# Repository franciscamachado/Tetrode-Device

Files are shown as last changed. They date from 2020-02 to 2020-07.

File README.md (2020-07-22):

# Tetrode-Device

We have developed a simple and affordable tetrode-based device that allows interchangeable extracellular recordings of neural activity between in vivo and ex vivo preparations and can be easily implemented in all wet-bench laboratories.

All

## Building Instructions
Construction and usage are described in the [paper](https://www.sciencedirect.com/science/article/pii/S0165027020301783).

**Assembly Parts:**

**(1) - Electrode Interface Board (EIB).** The EIB's gerber files are provided in the "Design" folder for three different headstages: (1) RHD32 (Intan/Open Ephys) ([link](https://github.com/franciscamachado/Tetrode-Device/tree/master/Designs/EIB/Eagle/OpenEphys)), (2) HS-36-LED (NeuraLynx) ([link](https://github.com/franciscamachado/Tetrode-Device/tree/master/Designs/EIB/Eagle/Neuralynx)) and (3) HST/32D Plexon ([link](https://github.com/franciscamachado/Tetrode-Device/tree/master/Designs/EIB/Eagle/Plexon)). Each EIB is provided intwo versions: the first with independent GND and REF and the second with shorted GND and REF. The EIB should be manufactured with electroless nickel immersion gold (ENIG) surface finishing.

**(2) - A79024-001 Omnetics connector** ([link](https://www.omnetics.com/products/neuro-connectors/nano-strip-connectors)). 

**(3) - Small gold pins** ([link](https://neuralynx.com/hardware/small-eib-pins)). 

**(4) - Tetrode guide.** The .STL files of the tetrode guide are available with 2 single track widths: 0.3 mm ([link](https://github.com/franciscamachado/Tetrode-Device/blob/master/Designs/Tetrode%20Guide/0.3mmTrack.stl)) and 0.6 mm ([link](https://github.com/franciscamachado/Tetrode-Device/blob/master/Designs/Tetrode%20Guide/0.6mmTrack.stl)). An .STL file for the tetrode guide with an optogenetic extention is also available ([link](https://github.com/franciscamachado/Tetrode-Device/tree/master/Designs/Tetrode%20Guide/Optogenetic%20Extension)). These designs are easily altered and adjusted to the size and number of tetrodes to be used.

**(5) - Tetrode wire** (depending on application).

## Citing this Work

When using this device, please cite the paper:

Francisca Machado, Nuno Sousa, Patricia Monteiro, Luis Jacinto (2020). A versatile and modular tetrode-based device for single-unit recordings in rodent ex vivo and in vivo acute preparations. J Neurosci Methods, 341:108755. [Link](https://www.sciencedirect.com/science/article/pii/S0165027020301783)

## License

<br />This work is licensed with a License <a rel="license" href="http://creativecommons.org/licenses/by-nc/4.0/">Creative Commons - Attribution-NonCommercial 4.0 International</a>.

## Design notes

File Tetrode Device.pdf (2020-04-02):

Tetrode Device | 1

1

Assembly Parts:
(1) – Electrode Interface Board (EIB). Link (https://github.com/franciscamachado/Tetrode-Device/tree/master/Designs/EIB)
(2) – A79024-001 Omnetics connector. Link (https://www.omnetics.com/products/neuro-connectors/nano-strip-connectors)
(3) – Small gold pins. Link (https://neuralynx.com/hardware/small-eib-pins)
(4) – Tetrode guide. Link (https://github.com/franciscamachado/Tetrode-Device/tree/master/Designs/Tetrode%20Guide)
(5) – Tetrode wire (determined by application).

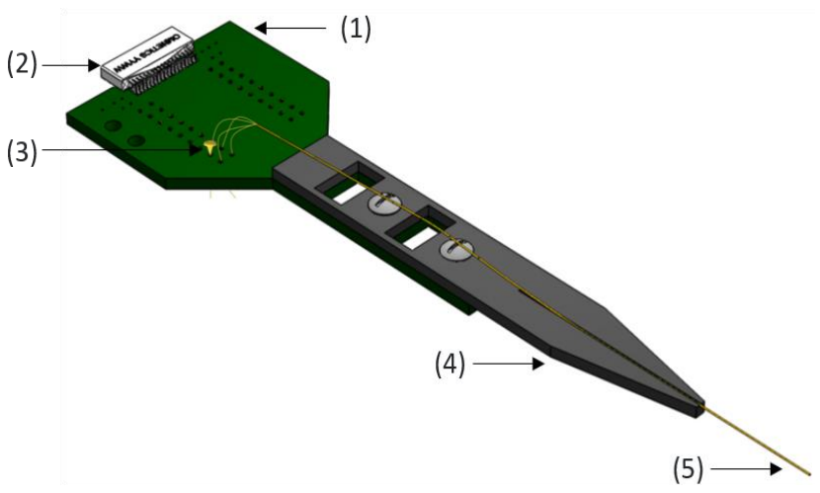
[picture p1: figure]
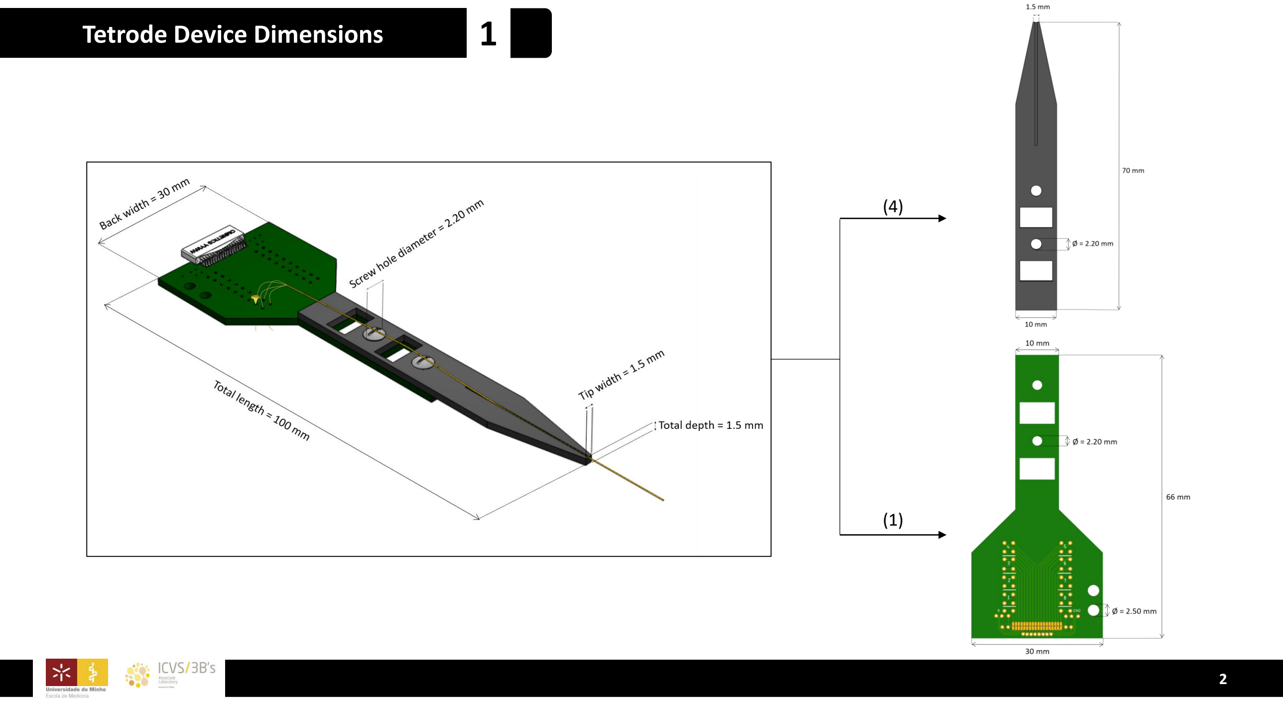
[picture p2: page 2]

Tetrode Device Dimensions | 1

2

(1)

(4)

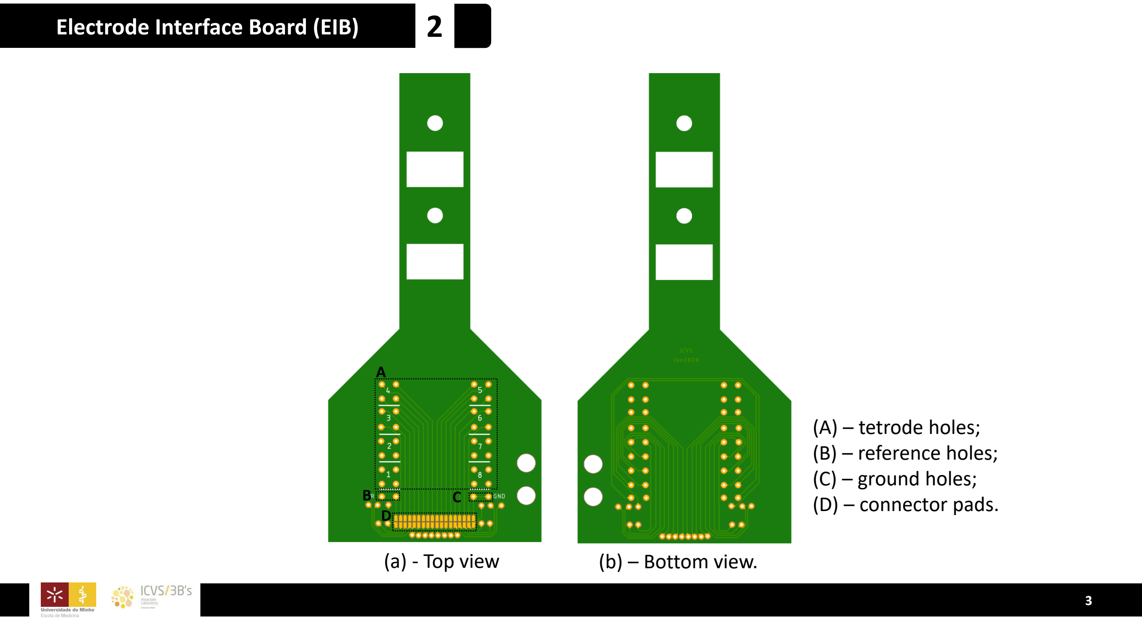
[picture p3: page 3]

Electrode Interface Board (EIB) 2

3

(A) – tetrode holes;
(B) – reference holes;
(C) – ground holes;
(D) – connector pads.
(a) - Top view | (b) – Bottom view.

A

B C
D

4

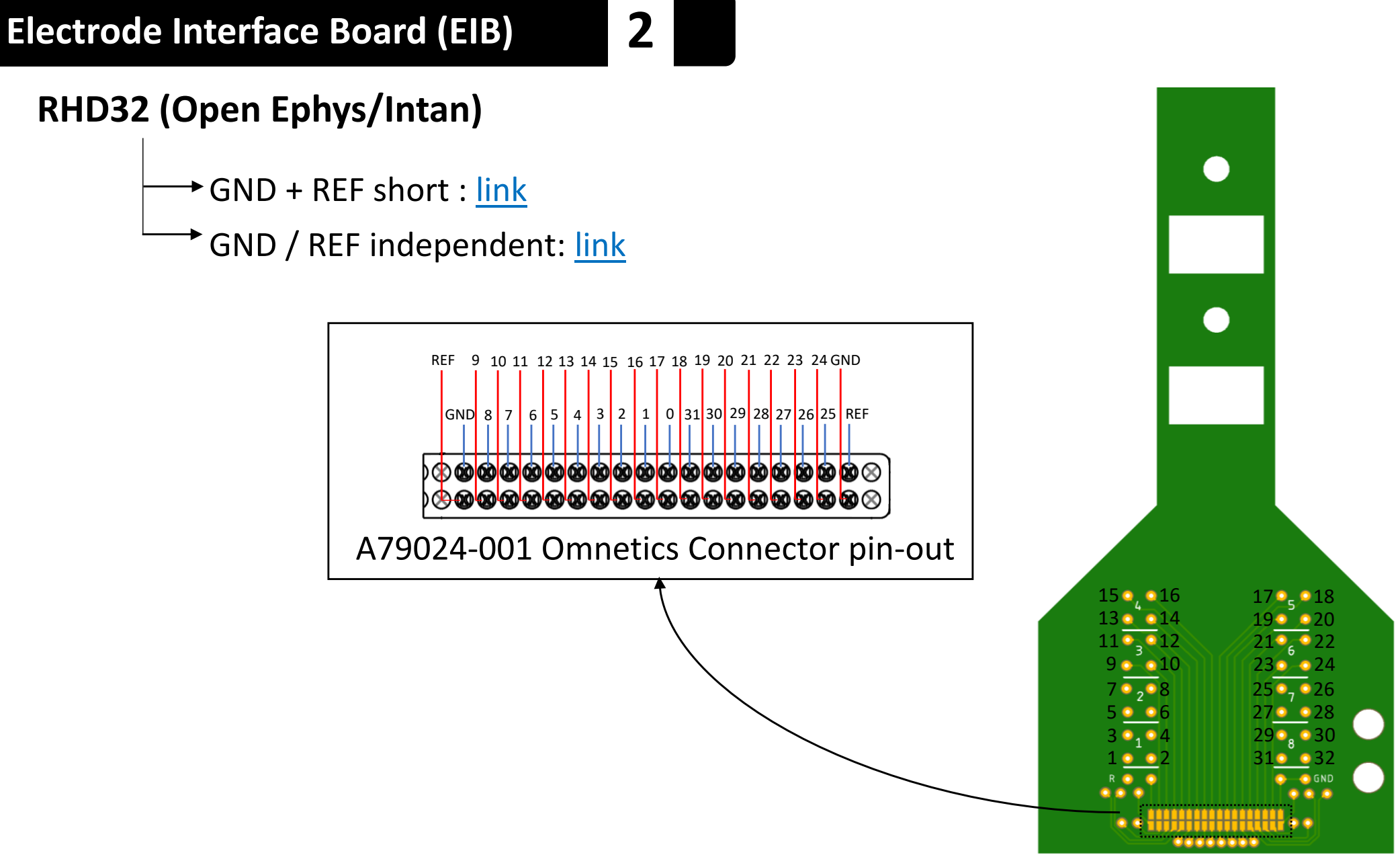
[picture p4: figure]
Electrode Interface Board (EIB); GND; REF; 24 GND; A79024-001 Omnetics Connector pin-out; RHD32 (Open Ephys/Intan); GND + REF short : link; GND / REF independent: link

(a) Top view

9 10 11 12 13 14 15 16 17 18 19 20 21 22 23

5

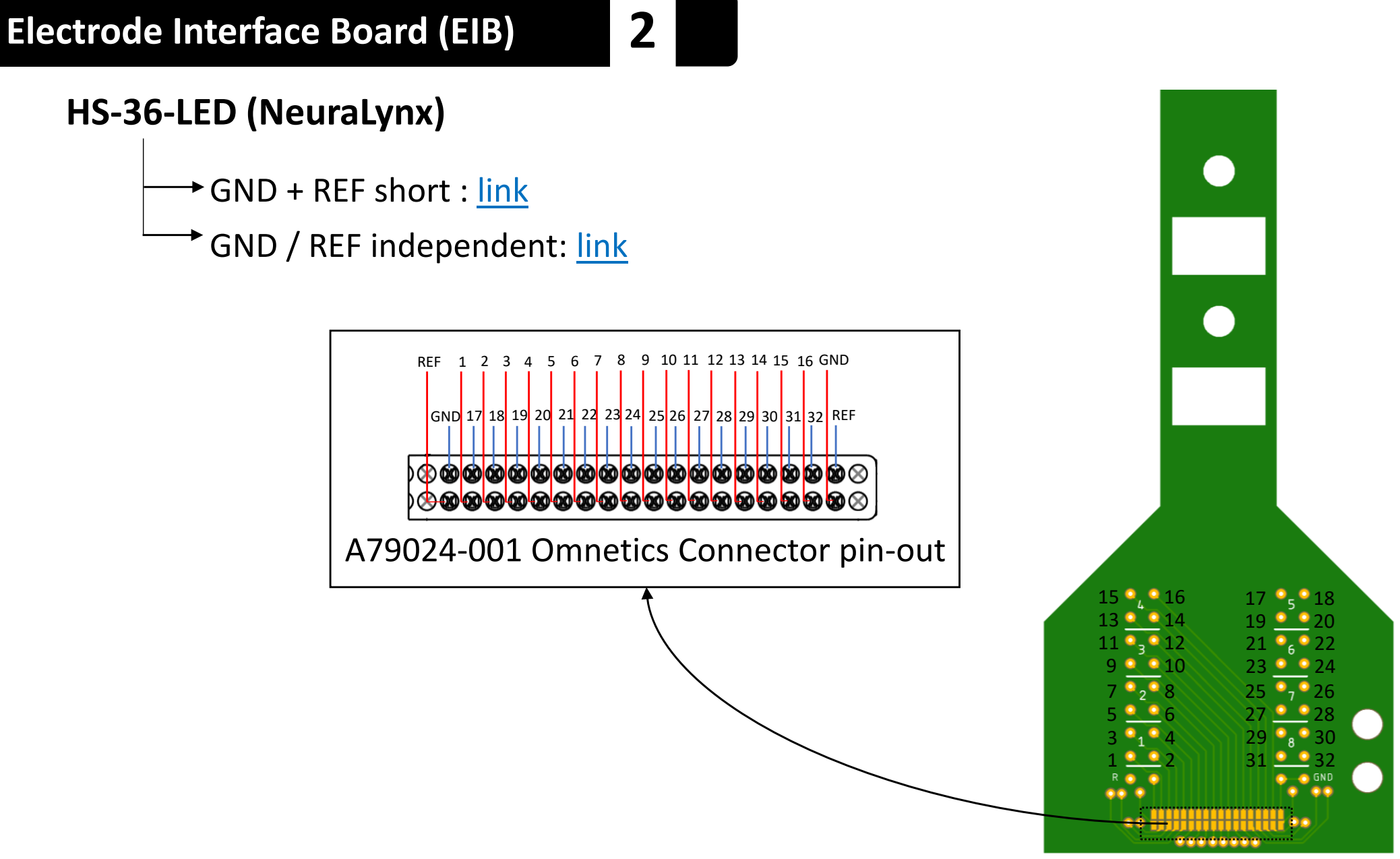
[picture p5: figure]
Electrode Interface Board (EIB); GND; REF; 8 9 10 11 12 13 14 15 16 GND; HS-36-LED (NeuraLynx); A79024-001 Omnetics Connector pin-out; GND + REF short : link; GND / REF independent: link

(a) Top view

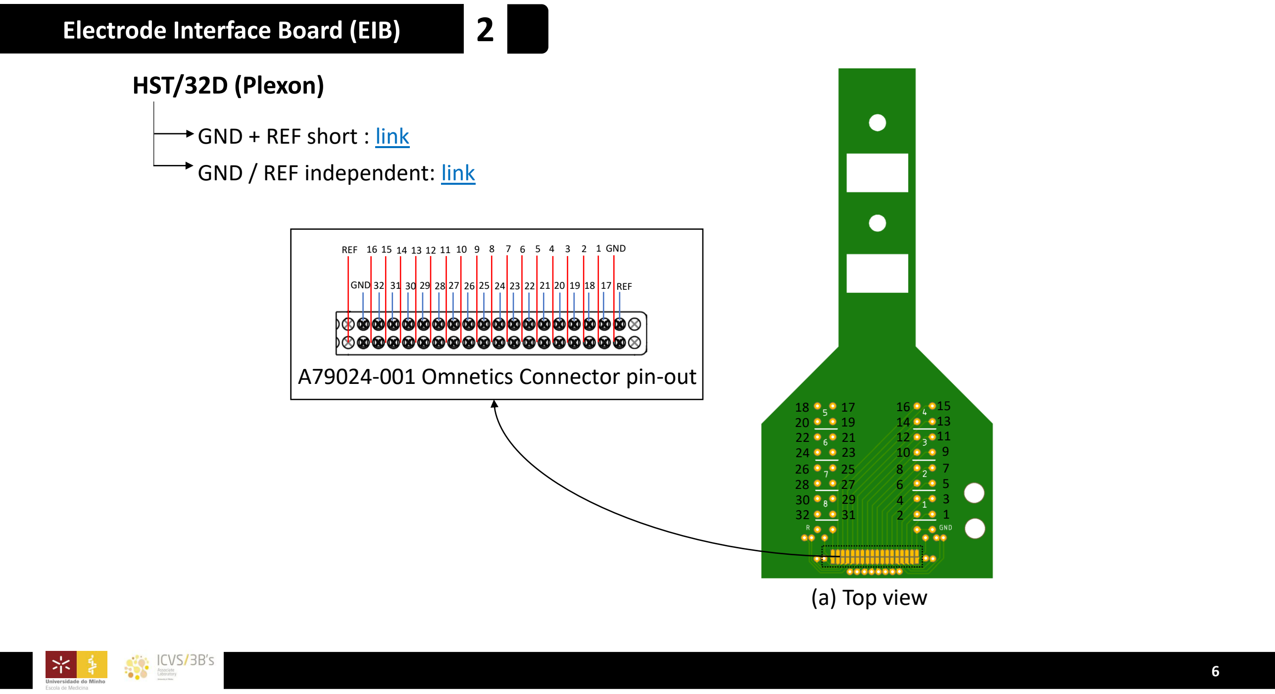
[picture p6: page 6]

Electrode Interface Board (EIB) 2

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
14 | 13
16 | 15
20 | 19
18 | 17
24 | 23
22 | 21
28 | 27
26 | 25
32 | 31
30 | 29
(a) Top view

HST/32D (Plexon)

REF 16 15 14 13 12 11 10 9 8 7 6 5 4 3 2 1 GND

GND 32 | 31 | 30 | 29 | 28 27 | 26 | 25 | 24 | 23 | 22 | 21 | 20 | 19 | 18 | 17 | REF

A79024-001 Omnetics Connector pin-out

GND + REF short : link (https://github.com/franciscamachado/Tetrode-Device/tree/master/Designs/EIB/Eagle/Plexon/GND%20%26%20REF%20shorted)
GND / REF independent: link (https://github.com/franciscamachado/Tetrode-Device/tree/master/Designs/EIB/Eagle/Plexon/GND%20%26%20REF)

Tetrode Guide | 3

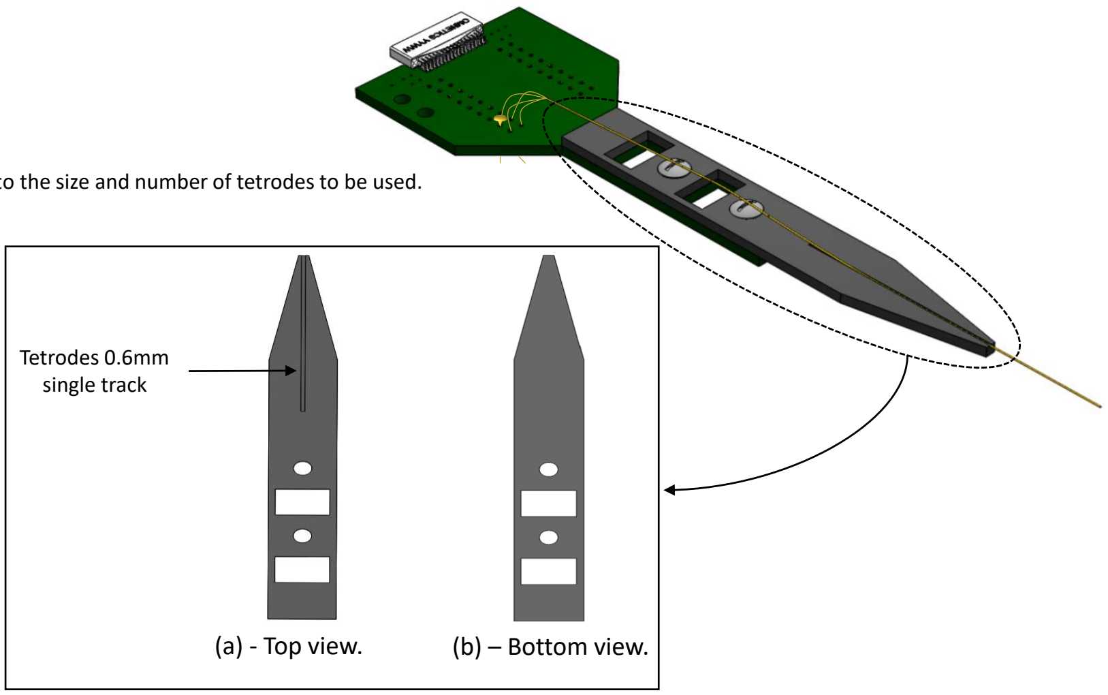
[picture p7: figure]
Tetrodes 0.6mm single track; (a) - Top view.; (b) – Bottom view.

7

Tetrode guide - single track example (holds 8x50µm tetrodes):
- length = 30 mm
- width = 0.6 mm
- depth= 0.6 mm

* These designs are easily altered and adjusted to the size and number of tetrodes to be used. Link (https://github.com/franciscamachado/Tetrode-Device/tree/master/Designs/Tetrode%20Guide)

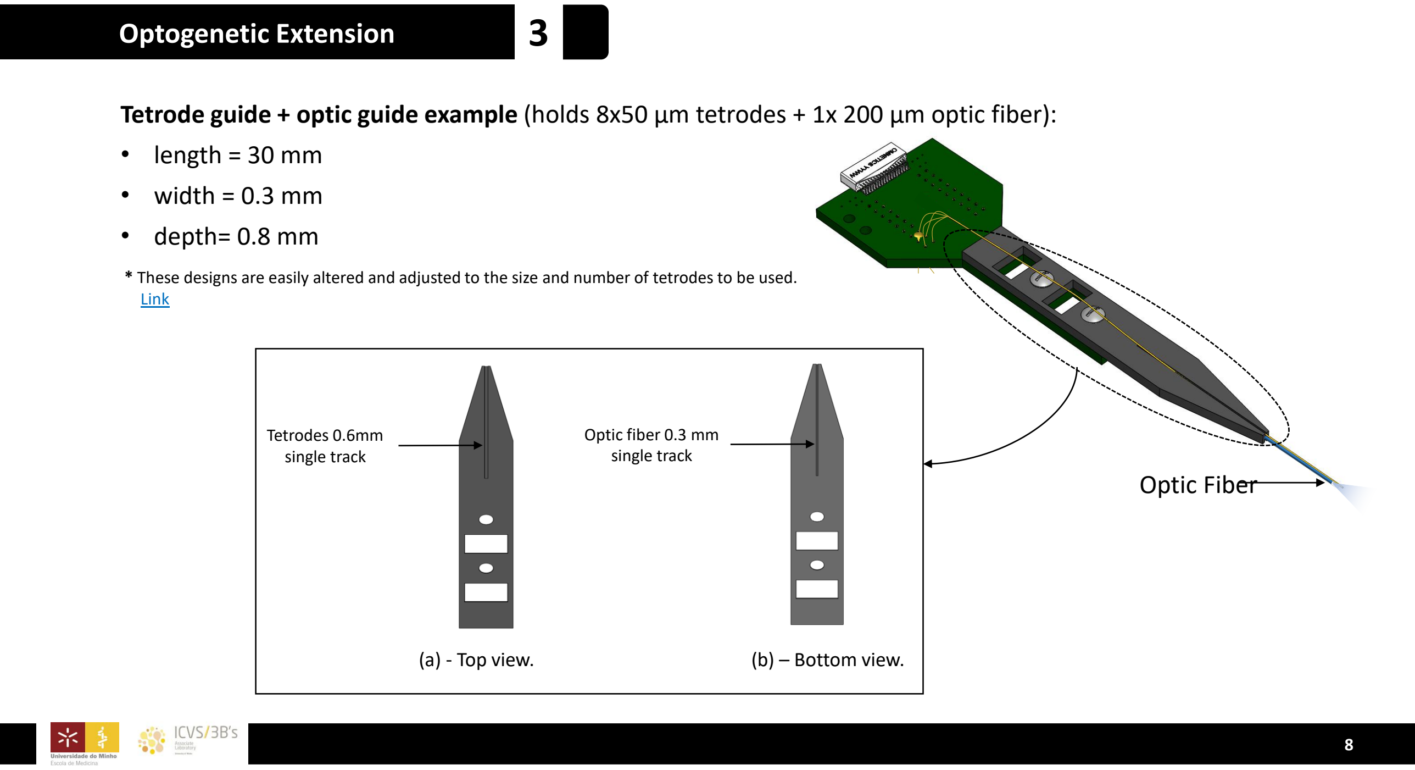
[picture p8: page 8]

Optic Fiber

Optogenetic Extension | 3

8

Tetrode guide + optic guide example (holds 8x50 µm tetrodes + 1x 200 µm optic fiber):
- length = 30 mm
- width = 0.3 mm
- depth= 0.8 mm
(a) - Top view. | (b) – Bottom view.

Tetrodes 0.6mm
single track

Optic fiber 0.3 mm
single track

* These designs are easily altered and adjusted to the size and number of tetrodes to be used. Link (https://github.com/franciscamachado/Tetrode-Device/tree/master/Designs/Tetrode%20Guide/Optogenetic%20Extension)

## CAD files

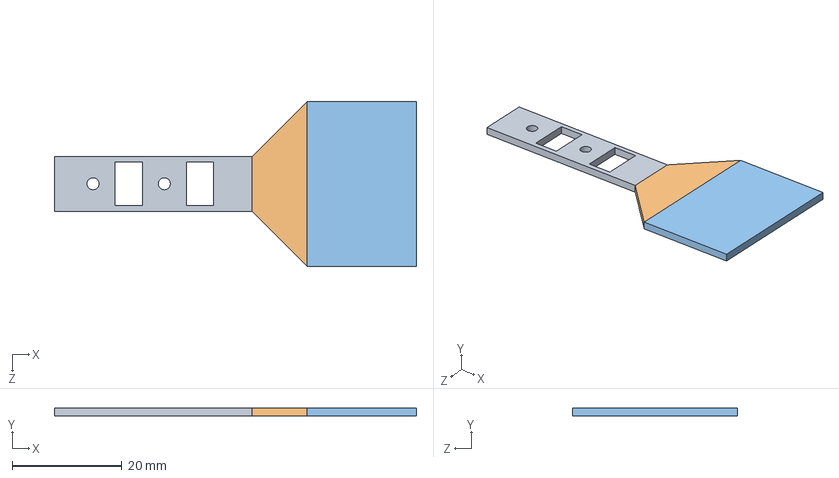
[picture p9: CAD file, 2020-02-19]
Designs/EIB/SolidWorks/EIB.SLDASM
66.0 x 1.50 x 30.0 mm
P1
P3
P2

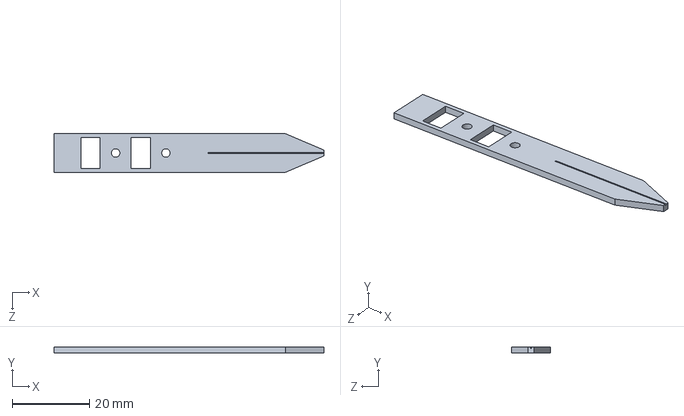
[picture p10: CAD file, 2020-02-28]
Designs/Tetrode Guide/0.3mmTrack.sldprt
70.0 x 1.50 x 10.0 mm

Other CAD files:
Designs/Tetrode Guide/Optogenetic Extension/0.6mmTrack_0.3mmTrack.SLDPRT
Designs/Tetrode Guide/0.6mmTrack.sldprt
Designs/Tetrode Guide/Optogenetic Extension/0.6mmTrack_0.5mmTrack.SLDPRT
Designs/EIB/SolidWorks/EIB.DXF
Designs/EIB/SolidWorks/EIB.SLDPRT
Designs/Tetrode Guide/0.3mmTrack.stl
Designs/Tetrode Guide/0.6mmTrack.stl
Designs/Tetrode Guide/Optogenetic Extension/0.6mmTrack_0.3mmTrack.STL
Designs/Tetrode Guide/Optogenetic Extension/0.6mmTrack_0.5mmTrack.STL

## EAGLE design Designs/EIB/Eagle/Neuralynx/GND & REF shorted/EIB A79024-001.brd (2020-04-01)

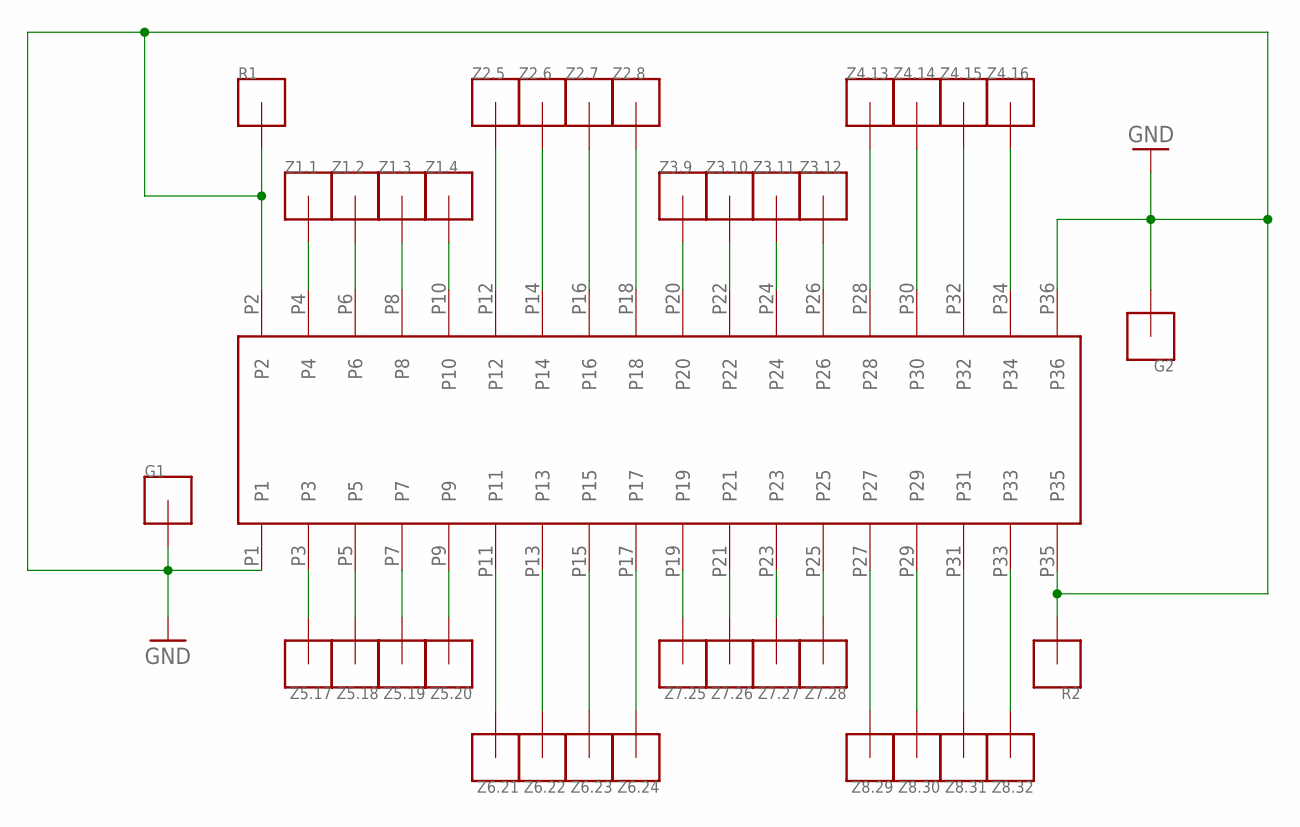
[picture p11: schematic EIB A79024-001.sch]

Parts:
A79024: OMNETICS; A79024
G1, G2: S_P_HOLE
R1, R2: S_P_HOLE
Z1.1, Z1.2, Z1.3, Z1.4, Z2.5, Z2.6, Z2.7, Z2.8, Z3.9, Z3.10, Z3.11, Z3.12, Z4.13, Z4.14, Z4.15, Z4.16, Z5.17, Z5.18, Z5.19, Z5.20, Z6.21, Z6.22, Z6.23, Z6.24, Z7.25, Z7.26, Z7.27, Z7.28, Z8.29, Z8.30, Z8.31, Z8.32: S_P_HOLE

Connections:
GND: A79024.P1, A79024.P2, A79024.P35, A79024.P36, G1.P1, G2.P1, R1.P1, R2.P1
unnamed: A79024.P4, Z1.1.P1
unnamed: A79024.P6, Z1.2.P1
unnamed: A79024.P8, Z1.3.P1
unnamed: A79024.P10, Z1.4.P1
unnamed: A79024.P12, Z2.5.P1
unnamed: A79024.P14, Z2.6.P1
unnamed: A79024.P16, Z2.7.P1
unnamed: A79024.P18, Z2.8.P1
unnamed: A79024.P20, Z3.9.P1
unnamed: A79024.P22, Z3.10.P1
unnamed: A79024.P24, Z3.11.P1
unnamed: A79024.P26, Z3.12.P1
unnamed: A79024.P28, Z4.13.P1
unnamed: A79024.P30, Z4.14.P1
unnamed: A79024.P32, Z4.15.P1
unnamed: A79024.P34, Z4.16.P1
unnamed: A79024.P33, Z8.32.P1
unnamed: A79024.P31, Z8.31.P1
unnamed: A79024.P29, Z8.30.P1
unnamed: A79024.P27, Z8.29.P1
unnamed: A79024.P25, Z7.28.P1
unnamed: A79024.P23, Z7.27.P1
unnamed: A79024.P21, Z7.26.P1
unnamed: A79024.P19, Z7.25.P1
unnamed: A79024.P17, Z6.24.P1
unnamed: A79024.P15, Z6.23.P1
unnamed: A79024.P13, Z6.22.P1
unnamed: A79024.P11, Z6.21.P1
unnamed: A79024.P9, Z5.20.P1
unnamed: A79024.P7, Z5.19.P1
unnamed: A79024.P5, Z5.18.P1
unnamed: A79024.P3, Z5.17.P1

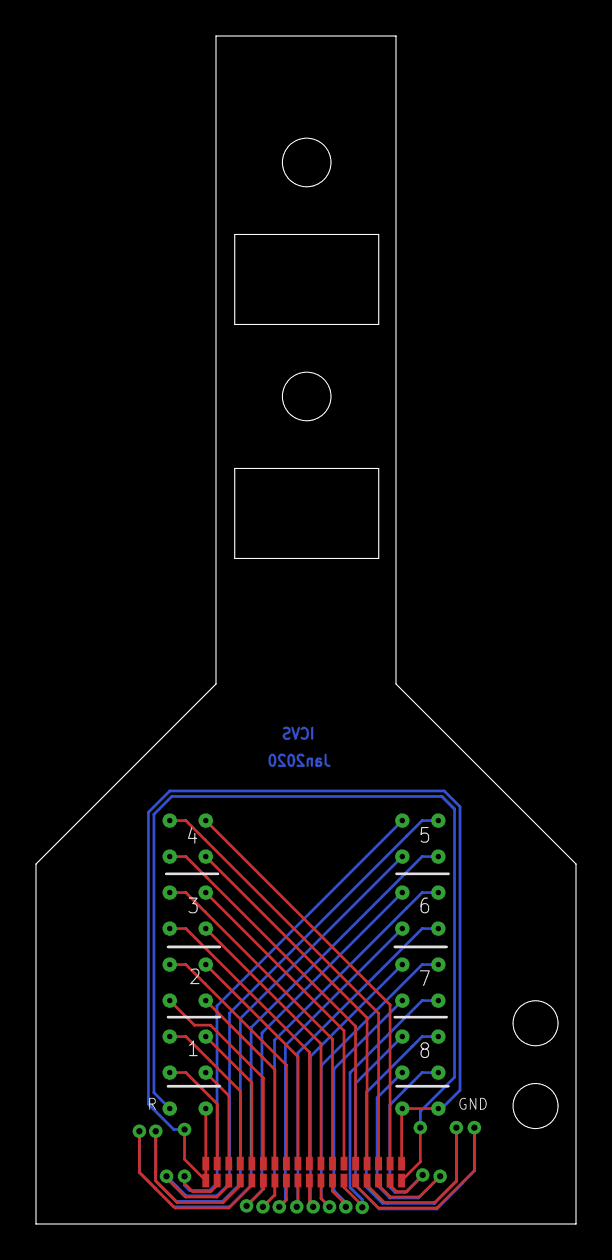
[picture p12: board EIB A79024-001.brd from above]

Board: 2 copper layers, 30.0 x 66.0 mm, 37 parts (0 on the bottom side), 33 nets.
